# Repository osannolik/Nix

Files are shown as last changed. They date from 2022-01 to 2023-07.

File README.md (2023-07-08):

# Yet another nixie tube clock

- IN-14 tubes
- DC3234 RTC keeps the time
- Software written in Rust running on STM32L0
- Can show time or temperature sent over Bluetooth using an external BLE-SPI-bridge
- Use whatever step-up converter you want to

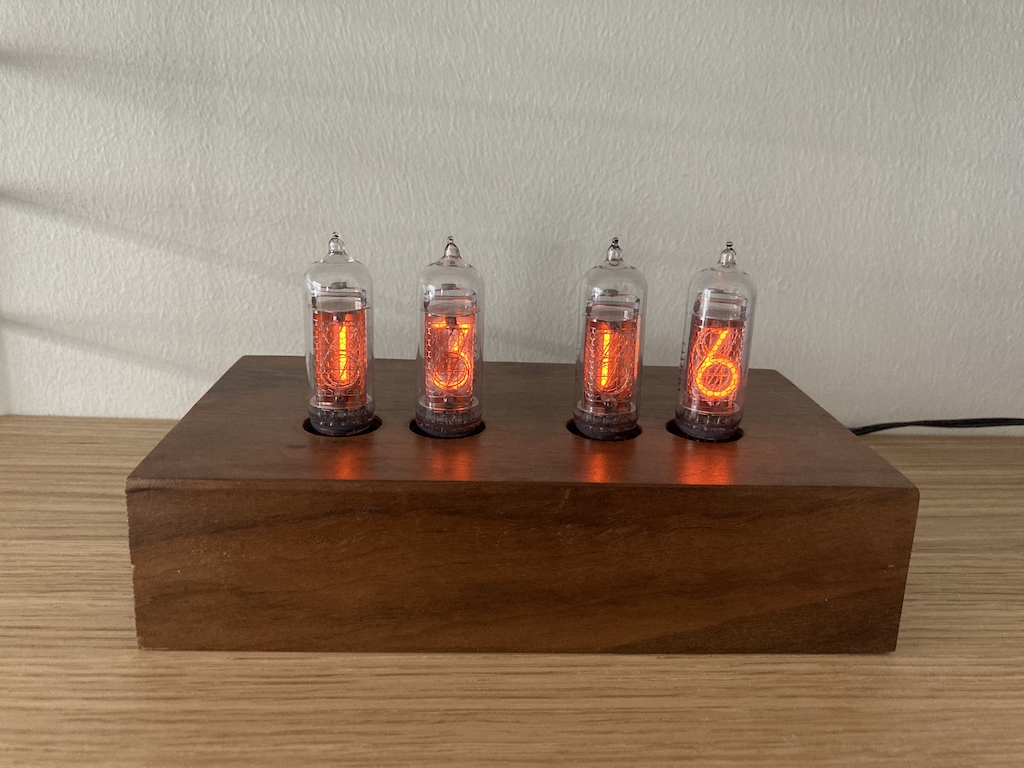
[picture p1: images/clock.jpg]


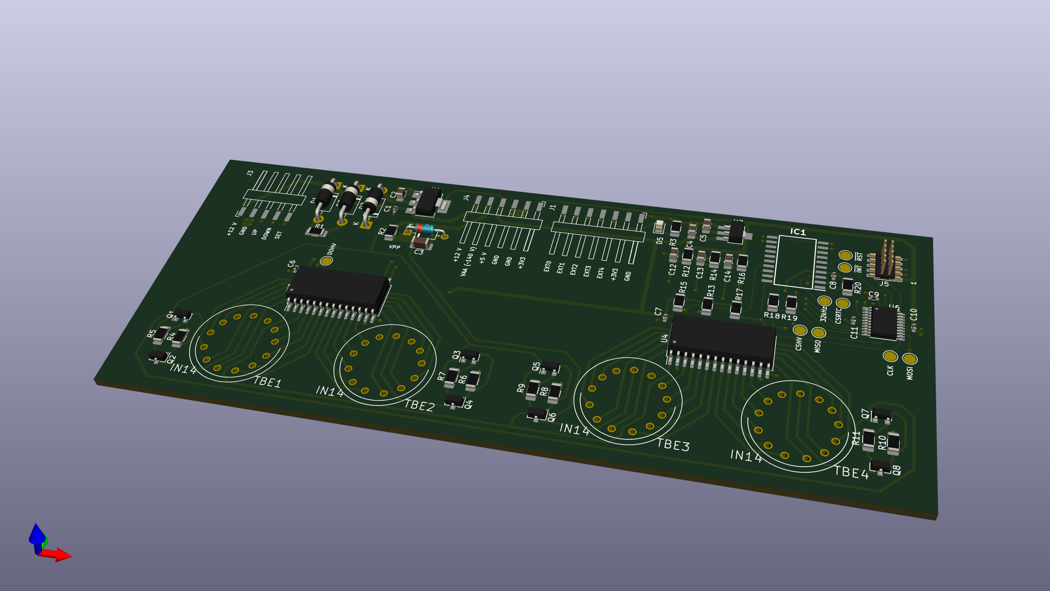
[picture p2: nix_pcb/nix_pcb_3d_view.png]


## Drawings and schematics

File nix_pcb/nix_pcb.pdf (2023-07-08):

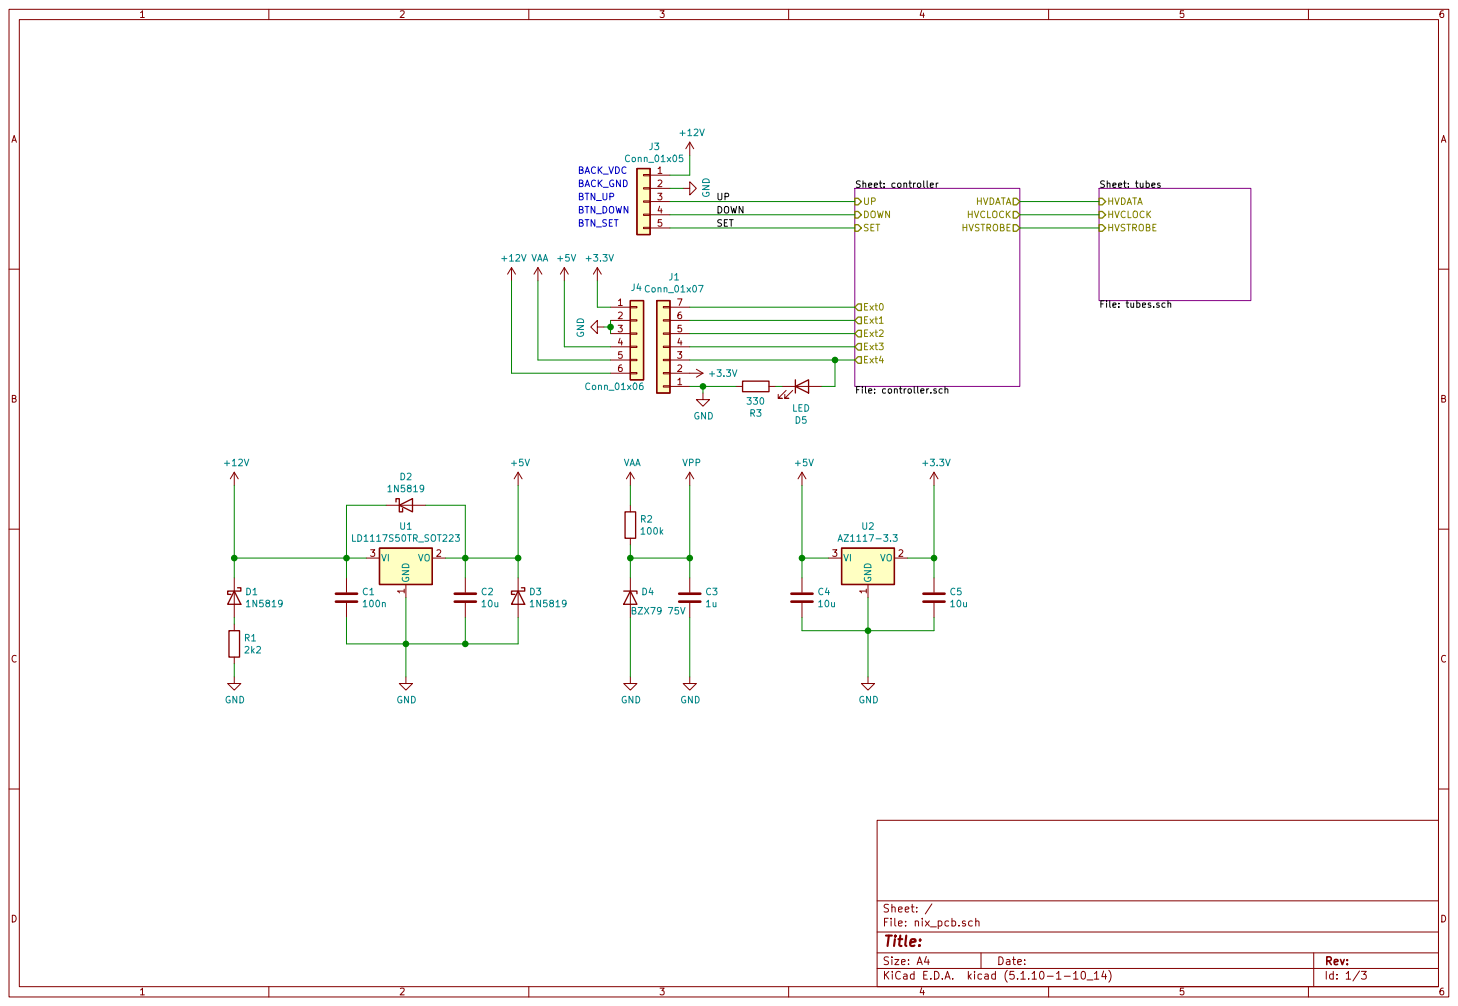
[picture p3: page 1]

Sheet: controller File: controller.sch UPDOWN

Sheet: tubes File: tubes.sch HVDATA HVCLOCK HVSTROBE

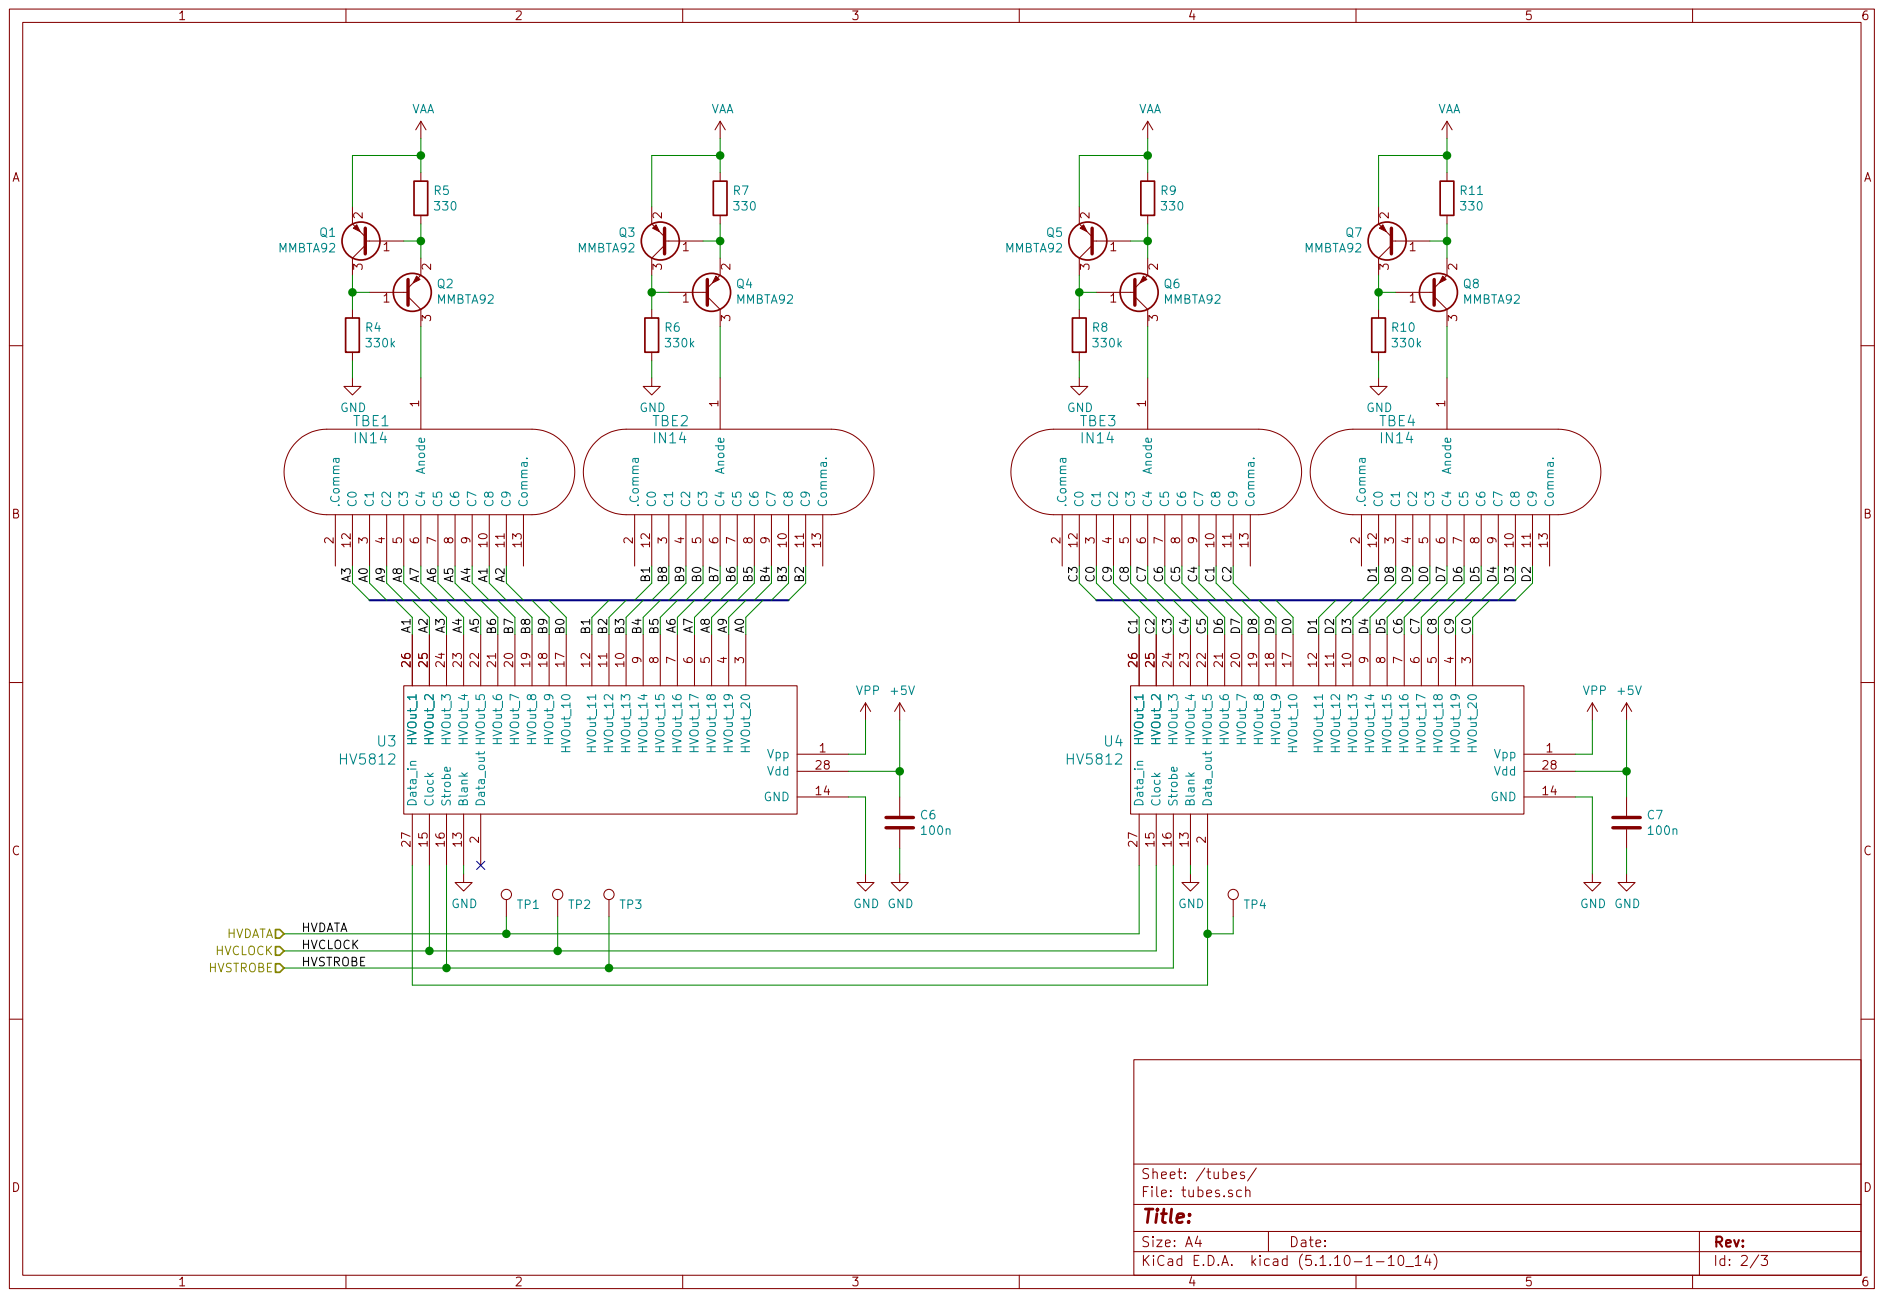
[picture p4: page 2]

Id: 2/3 Title: File: tubes.sch Sheet: /tubes/ Anode

9 U3 HV5812 Vpp HVOut_13 1 10 HVOut_12 11 HVOut_11 12 Blank 13 GND 14 Clock 15 Strobe 16 HVOut_10 17 HVOut_9 18 HVOut_8 19 Data_out 2 HVOut_7 20 HVOut_6 21 HVOut_5 22 HVOut_4 23 HVOut_3 24 HVOut_2 25 HVOut_1 26 Data_in 27 Vdd 28 HVOut_20

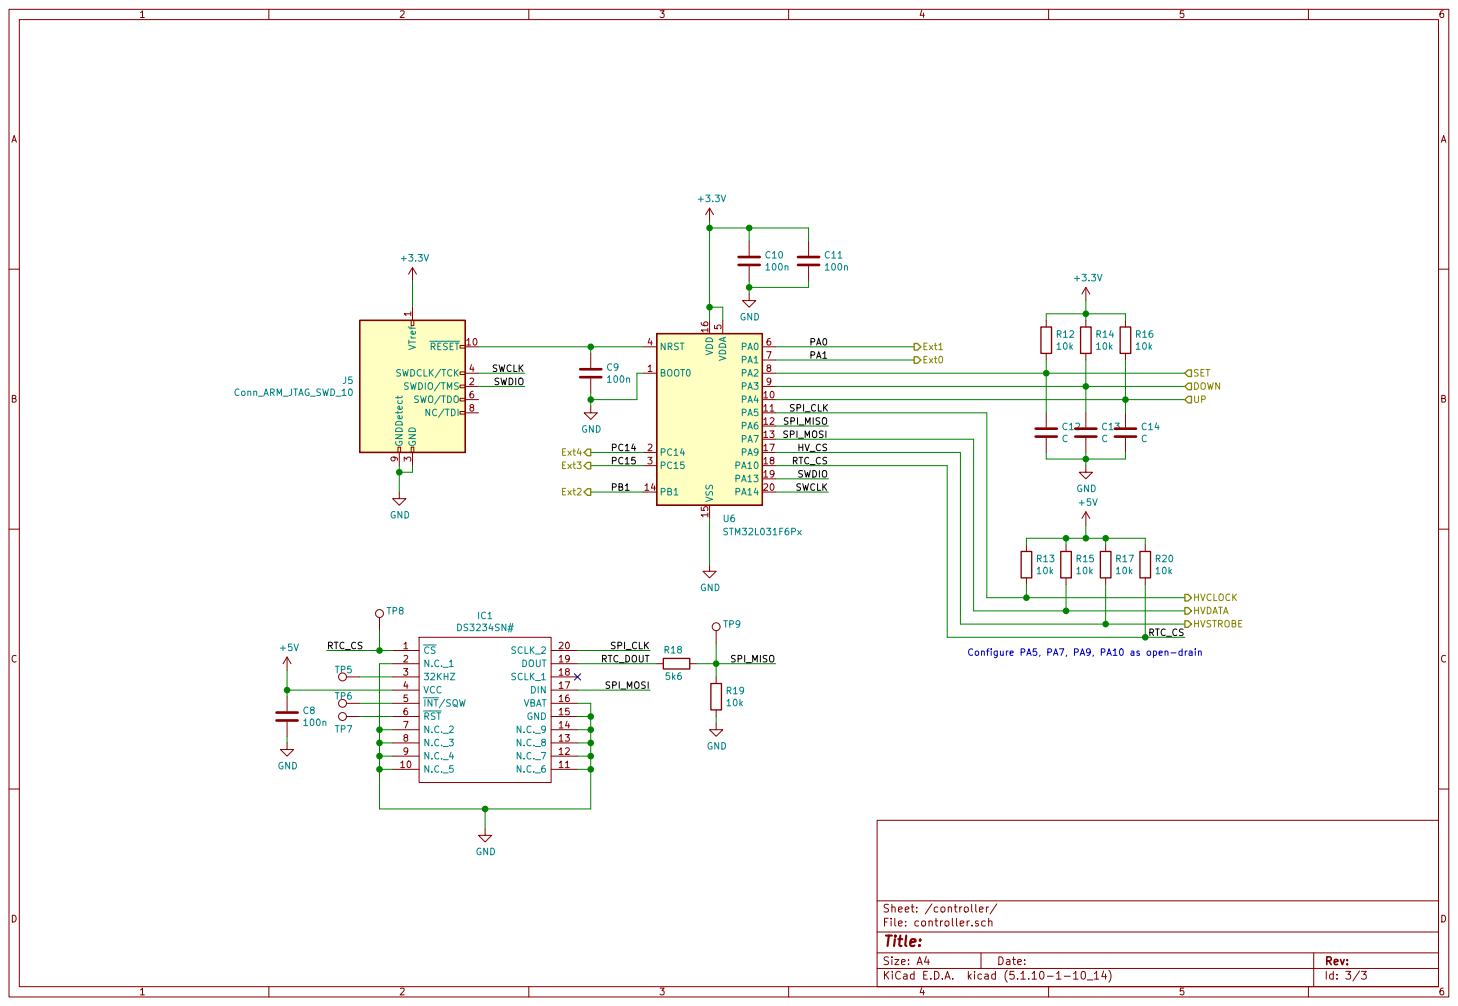
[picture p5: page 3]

SET HVDATA HVSTROBE HVCLOCK

3 SWDCLK/TCK 4 SWO/TDO 6 NC/TDI 8 GNDDetect 9

Id: 3/3 Title: File: controller.sch Sheet: /controller/ R19

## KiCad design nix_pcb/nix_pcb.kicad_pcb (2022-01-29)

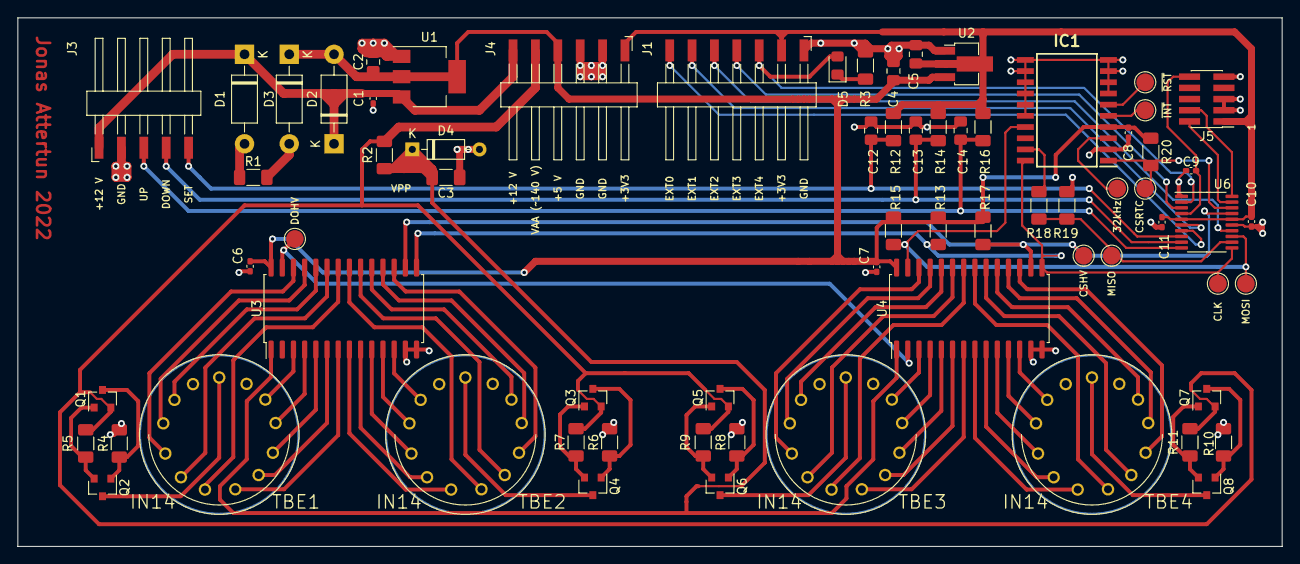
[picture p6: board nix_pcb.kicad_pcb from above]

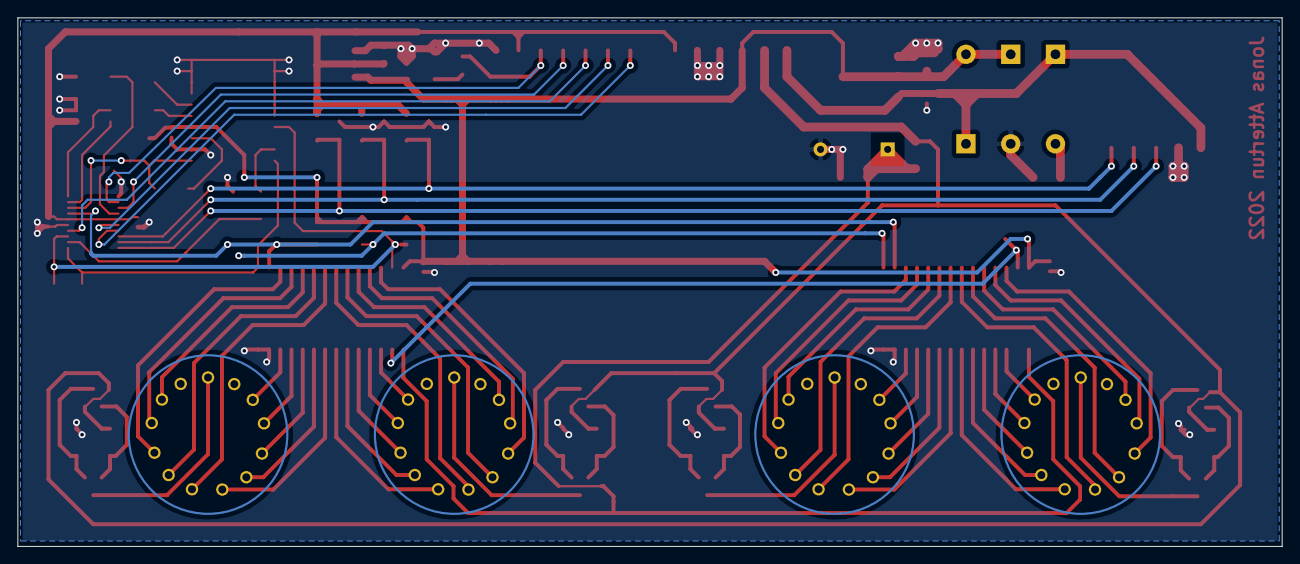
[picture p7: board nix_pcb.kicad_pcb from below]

Board: 2 copper layers, 143.5 x 60.0 mm, 70 parts (4 on the bottom side), 81 nets.

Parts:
C1, C6, C7, C8, C9, C10, C11: 100n; C_0402_1005Metric_Pad0.74x0.62mm_HandSolder
C2, C4, C5: 10u; C_0805_2012Metric_Pad1.18x1.45mm_HandSolder
C3: 1u; C_1206_3216Metric_Pad1.33x1.80mm_HandSolder
C12, C13, C14: C; C_0805_2012Metric_Pad1.18x1.45mm_HandSolder
D1, D2, D3: 1N5819; D_DO-41_SOD81_P10.16mm_Horizontal
D4: BZX79 75V; D_DO-35_SOD27_P7.62mm_Horizontal
D5: LED; LED_0805_2012Metric_Pad1.15x1.40mm_HandSolder
IC1: DS3234SN#; SOIC127P1032X265-20N
J1: Conn_01x07; Harwin_M20-89007xx_1x07_P2.54mm_Horizontal
J3: Conn_01x05; Harwin_M20-89005xx_1x05_P2.54mm_Horizontal
J4: Conn_01x06; Harwin_M20-89006xx_1x06_P2.54mm_Horizontal
J5: Conn_ARM_JTAG_SWD_10; PinHeader_2x05_P1.27mm_Vertical_SMD
Q1, Q2, Q3, Q4, Q5, Q6, Q7, Q8: MMBTA92; SOT-23
R1: 2k2; R_1206_3216Metric_Pad1.30x1.75mm_HandSolder
R2: 100k; R_1206_3216Metric_Pad1.30x1.75mm_HandSolder
R3, R5, R7, R9, R11: 330; R_1206_3216Metric_Pad1.30x1.75mm_HandSolder
R4, R6, R8, R10: 330k; R_1206_3216Metric_Pad1.30x1.75mm_HandSolder
R12, R13, R14, R15, R16, R17, R19, R20: 10k; R_1206_3216Metric_Pad1.30x1.75mm_HandSolder
R18: 5k6; R_1206_3216Metric_Pad1.30x1.75mm_HandSolder
TBE1, TBE2, TBE3, TBE4: IN14; IN-14-mod
TP1, TP2, TP3, TP4, TP5, TP6, TP7, TP8, TP9: TestPoint; TestPoint_Pad_D2.0mm
U1: LD1117S50TR_SOT223; SOT-223-3_TabPin2
U2: AZ1117-3.3; SOT-89-3_Handsoldering
U3, U4: HV5812; SOIC-28W_7.5x17.9mm_P1.27mm
U6: STM32L031F6Px; TSSOP-20_4.4x6.5mm_P0.65mm

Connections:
+3V3: C5.1, C10.1, C11.1, J1.2, J4.1, J5.1, R12.1, R14.1, R16.1, U2.2, U6.5, U6.16
+5V: C2.1, C4.1, C6.1, C7.1, C8.1, D2.2, D3.1, IC1.4, J4.4, R13.1, R15.1, R17.1, R20.1, U1.2, U2.3, U3.28, U4.28
+12V: C1.1, D1.1, D2.1, J3.1, J4.6, U1.3
/DOWN: C13.1, J3.4, R14.2, U6.9
/SET: C12.1, J3.5, R12.2, U6.8
/UP: C14.1, J3.3, R16.2, U6.10
/controller/Ext0: J1.7, U6.7
/controller/Ext1: J1.6, U6.6
/controller/Ext2: J1.5, U6.14
/controller/Ext3: J1.4, U6.3
/controller/Ext4: D5.2, J1.3, U6.2
/controller/HVCLOCK: IC1.20, R13.2, TP2.1, U3.15, U4.15, U6.11
/controller/HVDATA: IC1.17, R15.2, TP1.1, U4.27, U6.13
/controller/HVSTROBE: R17.2, TP3.1, U3.16, U4.16, U6.17
/controller/RTC_CS: IC1.1, R20.2, TP8.1, U6.18
/controller/RTC_DOUT: IC1.19, R18.1
/controller/SPI_MISO: R18.2, R19.1, TP9.1, U6.12
/controller/SWCLK: J5.4, U6.20
/controller/SWDIO: J5.2, U6.19
/tubes/A0: TBE1.3, U3.3
/tubes/A1: TBE1.10, U3.26
/tubes/A2: TBE1.11, U3.25
/tubes/A3: TBE1.12, U3.24
/tubes/A4: TBE1.9, U3.23
/tubes/A5: TBE1.8, U3.22
/tubes/A6: TBE1.7, U3.7
/tubes/A7: TBE1.6, U3.6
/tubes/A8: TBE1.5, U3.5
/tubes/A9: TBE1.4, U3.4
/tubes/B0: TBE2.5, U3.17
/tubes/B1: TBE2.12, U3.12
/tubes/B2: TBE2.11, U3.11
/tubes/B3: TBE2.10, U3.10
/tubes/B4: TBE2.9, U3.9
/tubes/B5: TBE2.8, U3.8
/tubes/B6: TBE2.7, U3.21
/tubes/B7: TBE2.6, U3.20
/tubes/B8: TBE2.3, U3.19
/tubes/B9: TBE2.4, U3.18
/tubes/C0: TBE3.3, U4.3
/tubes/C1: TBE3.10, U4.26
/tubes/C2: TBE3.11, U4.25
/tubes/C3: TBE3.12, U4.24
/tubes/C4: TBE3.9, U4.23
/tubes/C5: TBE3.8, U4.22
/tubes/C6: TBE3.7, U4.7
/tubes/C7: TBE3.6, U4.6
/tubes/C8: TBE3.5, U4.5
/tubes/C9: TBE3.4, U4.4
/tubes/D0: TBE4.5, U4.17
/tubes/D1: TBE4.12, U4.12
/tubes/D2: TBE4.11, U4.11
/tubes/D3: TBE4.10, U4.10
/tubes/D4: TBE4.9, U4.9
/tubes/D5: TBE4.8, U4.8
/tubes/D6: TBE4.7, U4.21
/tubes/D7: TBE4.6, U4.20
/tubes/D8: TBE4.3, U4.19
/tubes/D9: TBE4.4, U4.18
GND: C1.2, C2.2, C3.2, C4.2, C5.2, C6.2, C7.2, C8.2, C9.2, C10.2, C11.2, C12.2, C13.2, C14.2, D3.2, D4.2, IC1.2, IC1.7, IC1.8, IC1.9, IC1.10, IC1.11, IC1.12, IC1.13, IC1.14, IC1.15, IC1.16, J1.1, J3.2, J4.2, J4.3, J5.3, J5.5, J5.9, R1.2, R3.1, R4.2, R6.2, R8.2, R10.2, R19.2, U1.1, U2.1, U3.13, U3.14, U4.13, U4.14, U6.1, U6.15
unnamed: C9.1, J5.10, U6.4
unnamed: D1.2, R1.1
unnamed: D5.1, R3.2
unnamed: IC1.3, TP5.1
unnamed: IC1.5, TP6.1
unnamed: IC1.6, TP7.1
unnamed: Q1.1, Q2.2, R5.2
unnamed: Q1.3, Q2.1, R4.1
unnamed: Q2.3, TBE1.1
unnamed: Q3.1, Q4.2, R7.2
unnamed: Q3.3, Q4.1, R6.1
unnamed: Q4.3, TBE2.1
unnamed: Q5.1, Q6.2, R9.2
unnamed: Q5.3, Q6.1, R8.1
unnamed: Q6.3, TBE3.1
unnamed: Q7.1, Q8.2, R11.2
unnamed: Q7.3, Q8.1, R10.1
unnamed: Q8.3, TBE4.1
unnamed: TP4.1, U3.27, U4.2
VAA: J4.5, Q1.2, Q3.2, Q5.2, Q7.2, R2.1, R5.1, R7.1, R9.1, R11.1
VPP: C3.1, D4.1, R2.2, U3.1, U4.1

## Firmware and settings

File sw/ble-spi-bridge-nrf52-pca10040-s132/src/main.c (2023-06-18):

#include <stdint.h>
#include <string.h>

#include "nrf_sdh.h"
#include "nrf_sdh_ble.h"
#include "nrf_pwr_mgmt.h"
#include "boards.h"
#include "ble.h"
#include "ble_advertising.h"
#include "nrf_ble_scan.h"
#include "nrf_delay.h"
#include "app_timer.h"

#include "soft_spi.h"

#define SPI_SCK_PIN  12
#define SPI_MISO_PIN 14
#define SPI_MOSI_PIN 13
#define SPI_SS_PIN   29

#define EXPECTED_NAME "sat"

#define CENTRAL_SCANNING_LED            BSP_BOARD_LED_0
#define CENTRAL_CONNECTED_LED           BSP_BOARD_LED_1
#define LEDBUTTON_LED                   BSP_BOARD_LED_2

#define APP_BLE_CONN_CFG_TAG            1
#define APP_BLE_OBSERVER_PRIO           3

static spi_buffer_t soft_spi;

APP_TIMER_DEF(update_timer);

NRF_BLE_SCAN_DEF(s_scan);

void assert_nrf_callback(uint16_t line_num, const uint8_t * p_file_name) {
  app_error_handler(0xDEADBEEF, line_num, p_file_name);
}

static void leds_init(void) {
  bsp_board_init(BSP_INIT_LEDS);

  bsp_board_leds_on();
}

static void scan_start(void) {
  ret_code_t err_code;

  err_code = nrf_ble_scan_start(&s_scan);
  APP_ERROR_CHECK(err_code);

//    bsp_board_led_off(CENTRAL_CONNECTED_LED);
//    bsp_board_led_on(CENTRAL_SCANNING_LED);
}

static void ble_evt_handler(ble_evt_t const * p_ble_evt, void * p_context) { }

static void ble_stack_init(void) {
  ret_code_t err_code;

  err_code = nrf_sdh_enable_request();
  APP_ERROR_CHECK(err_code);

  // Configure the BLE stack using the default settings.
  // Fetch the start address of the application RAM.
  uint32_t ram_start = 0;
  err_code = nrf_sdh_ble_default_cfg_set(APP_BLE_CONN_CFG_TAG, &ram_start);
  APP_ERROR_CHECK(err_code);

  // Enable BLE stack.
  err_code = nrf_sdh_ble_enable(&ram_start);
  APP_ERROR_CHECK(err_code);

  // Register a handler for BLE events.
  NRF_SDH_BLE_OBSERVER(m_ble_observer, APP_BLE_OBSERVER_PRIO, ble_evt_handler, NULL);
}

static void scan_evt_handler(scan_evt_t const * p_scan_evt) {
  const nrf_ble_scan_evt_filter_match_t match = p_scan_evt->params.filter_match;

  switch(p_scan_evt->scan_evt_id) {

    case NRF_BLE_SCAN_EVT_FILTER_MATCH:
      if (match.filter_match.name_filter_match) {
        uint8_t *mdata = ble_advdata_parse(match.p_adv_report->data.p_data,
                                           match.p_adv_report->data.len,
                                           BLE_GAP_AD_TYPE_MANUFACTURER_SPECIFIC_DATA);
        if (mdata) {
          soft_spi_put_data(&soft_spi, &mdata[MDATA_OFFSET]);
          bsp_board_led_invert(CENTRAL_SCANNING_LED);
        }
      }
      break;

    default:
      break;
  }
}

static void power_management_init(void) {
  ret_code_t err_code;
  err_code = nrf_pwr_mgmt_init();
  APP_ERROR_CHECK(err_code);
}

static void scan_init(const char* expected_name) {
  nrf_ble_scan_init_t init_scan;

  memset(&init_scan, 0, sizeof(init_scan));

  init_scan.connect_if_match = false;
  init_scan.conn_cfg_tag     = APP_BLE_CONN_CFG_TAG;

  ret_code_t err_code = nrf_ble_scan_init(&s_scan, &init_scan, scan_evt_handler);
  APP_ERROR_CHECK(err_code);

  err_code = nrf_ble_scan_filters_enable(&s_scan, NRF_BLE_SCAN_NAME_FILTER, false);
  APP_ERROR_CHECK(err_code);

  err_code = nrf_ble_scan_filter_set(&s_scan, SCAN_NAME_FILTER, expected_name);
  APP_ERROR_CHECK(err_code);
}

static void idle_state_handle(void) {
  nrf_pwr_mgmt_run();
}

void update(void * p_context) {
  (void) p_context;
  (void) soft_spi_write_buffer(&soft_spi);
}

int main(void) {
  leds_init();
  power_management_init();

  app_timer_init();
  app_timer_create(&update_timer, APP_TIMER_MODE_REPEATED, update);

  soft_spi_init(&soft_spi, SPI_SS_PIN, SPI_MOSI_PIN, SPI_SCK_PIN);
  ble_stack_init();
  scan_init(EXPECTED_NAME);
  scan_start();

  //bsp_board_led_on(CENTRAL_SCANNING_LED);
  //bsp_board_led_on(CENTRAL_CONNECTED_LED);

  int8_t err_code = app_timer_start(update_timer, APP_TIMER_TICKS(100), NULL);
  APP_ERROR_CHECK(err_code);

  while(true) {
    idle_state_handle();
  }
}

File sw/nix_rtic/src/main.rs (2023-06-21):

#![no_main]
#![no_std]

mod bcd;
mod board;
mod buttons;
mod ds3234;
mod ext;
mod mode;
mod nixieclock;
mod nixiedigits;
mod temperature;
mod time;

//use panic_rtt_target as _;
//use rtt_target::{rprintln, rtt_init_print};
//use cortex_m_semihosting::hprintln;
use panic_halt as _; // you can put a breakpoint on `rust_begin_unwind` to catch panics

use rtic::app;

use stm32l0xx_hal::pac;
use systick_monotonic::{fugit::Duration, Systick};

#[app(
    device = stm32l0xx_hal::pac,
    peripherals = true,
    dispatchers = [SPI1],
)]
mod app {
    use super::*;
    use crate::board::setup_peripherals;
    use crate::ext::{External, ExternalData};
    use crate::nixieclock::NixieClock;
    use systick_monotonic::fugit::ExtU32;

    // Setting this monotonic as the default
    #[monotonic(binds = SysTick, default = true)]
    type Tonic = Systick<1000>;
    type TonicTime = Duration<u64, 1, 1000>;

    #[local]
    struct Local {
        nixie: NixieClock,
        external: External,
    }

    #[shared]
    struct Shared {
        external_data: Option<ExternalData>,
    }

    #[init]
    fn init(cx: init::Context) -> (Shared, Local, init::Monotonics) {
        let dp: pac::Peripherals = cx.device;

        //        rtt_init_print!();
        //        rprintln!("hello");

        let (nixie_peripherals, ext_pins) = setup_peripherals(dp);

        let nixie = NixieClock::new(nixie_peripherals);
        let external = External::new(ext_pins);

        let mono = Systick::new(cx.core.SYST, 16_000_000);

        let _ = main::spawn_after(TonicTime::from_ticks(500));

        (
            Shared {
                external_data: None,
            },
            Local { nixie, external },
            init::Monotonics(mono),
        )
    }

    #[task(priority = 1, local = [nixie], shared = [external_data])]
    fn main(mut ctx: main::Context) {
        let next_time = monotonics::now() + 100.millis();

        let mut external_data: Option<ExternalData> = None;
        ctx.shared.external_data.lock(|r| {
            external_data = *r;
        });

        ctx.local.nixie.update(&external_data);

        let _ = main::spawn_at(next_time);
    }

    #[task(priority = 2, binds = EXTI0_1, local = [external], shared = [external_data])]
    fn exti_interrupt(mut ctx: exti_interrupt::Context) {
        //let exti_interrupt::LocalResources { external_temperature } = ctx.local;

        if let Some(data) = ctx.local.external.on_interrupt() {
            ctx.shared.external_data.lock(|r| {
                *r = Some(data);
            });
        }
    }
}

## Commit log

2022-01-26 first ds3234 design
    [controller.sch, nix_pcb.kicad_pcb, nix_pcb.sch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]
2022-01-29 removed button board
    [nix_pcb.kicad_pcb, nix_pcb.sch]
2022-01-29 add gnd to ext-conn and add silkscreen text to connectors
    [nix_pcb.kicad_pcb, nix_pcb.sch]
2022-01-29 add margin to vaa pin of zener
    [nix_pcb.kicad_pcb]
2022-11-08 Add a backplate draft
    [nix_backplate.kicad_pcb, nix_backplate.sch]
2022-11-10 Adjustments and text to backplate
    [nix_backplate.kicad_pcb]
2022-11-10 Ordered backplate
    [nix_backplate.kicad_pcb]
2022-12-11 reset seconds when setting minutes and hours
    [main.rs]
2023-02-09 Add initial ble to spi bridge sw
2023-02-16 Write manufacturer data to spi
2023-06-18 Use much slower SPI clock for ble-spi bridge - soft-spi since lowest allowed by hw is still too fast.
    [main.c, soft_spi.c, soft_spi.h]
2023-06-19 Add external temperature mode
2023-06-19 Show temperature from ext - forced to use software spi...
2023-06-21 Refactor to hide some interrupt handling
2023-07-08 pcb outputs
